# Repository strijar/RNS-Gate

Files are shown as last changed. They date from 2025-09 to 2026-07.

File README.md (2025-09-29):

# RNS-Gate

## Objective

Create a standalone device for access and routing within the Reticulum Network Stack 

## Interfaces for accessing other network nodes

* Integrated:
  - LoRa module (E22/E32 via SPI)
  - WiFi
  - Bluetooth
  - 10/100 Ethernet
* External:
  - RNode (via USB or Bluetooth)
  - WiFi in monitor mode (via USB)
* Audio access and PTT control for connecting analog VHF and HF radios with soft modem implementation 
* Connection of DMR stations via USB (OpenGD77 firmware) 

## Access to user devices

* BlueTooth 
* IP via WiFi and Ethernet

## Implementation

A 3-component "tower":

* Single-board computer based on Orange Pi Zero 
* Add-on board with an E22/E32 LoRa module 
* Add-on board with an HF/VHF audio interface

## Device configuration

Web interface over IP

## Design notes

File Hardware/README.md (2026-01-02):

# RNS-Gate Hardware

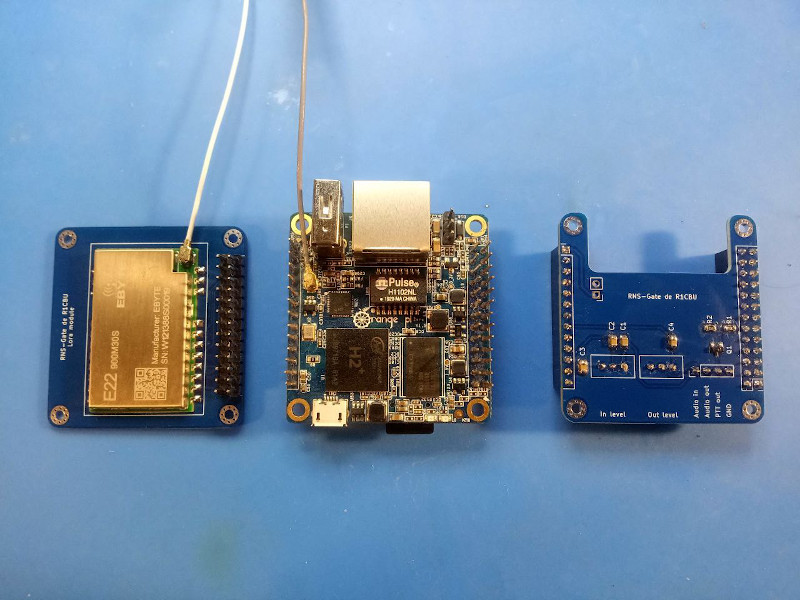
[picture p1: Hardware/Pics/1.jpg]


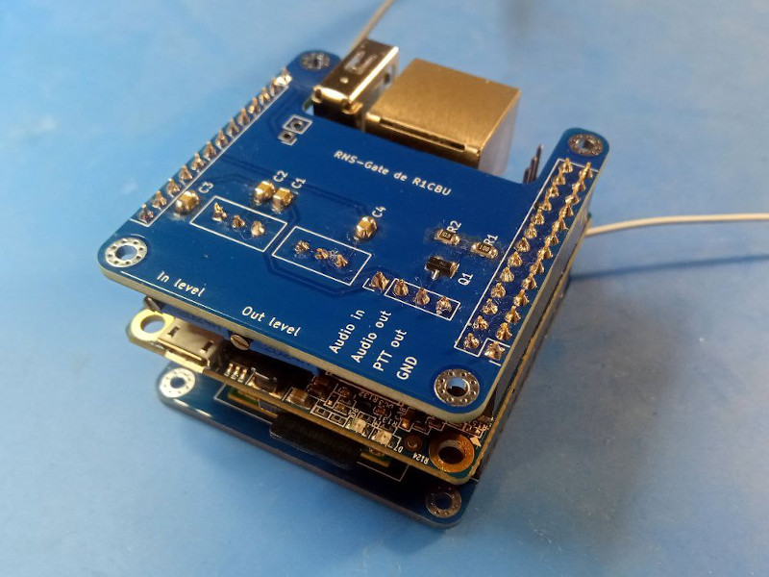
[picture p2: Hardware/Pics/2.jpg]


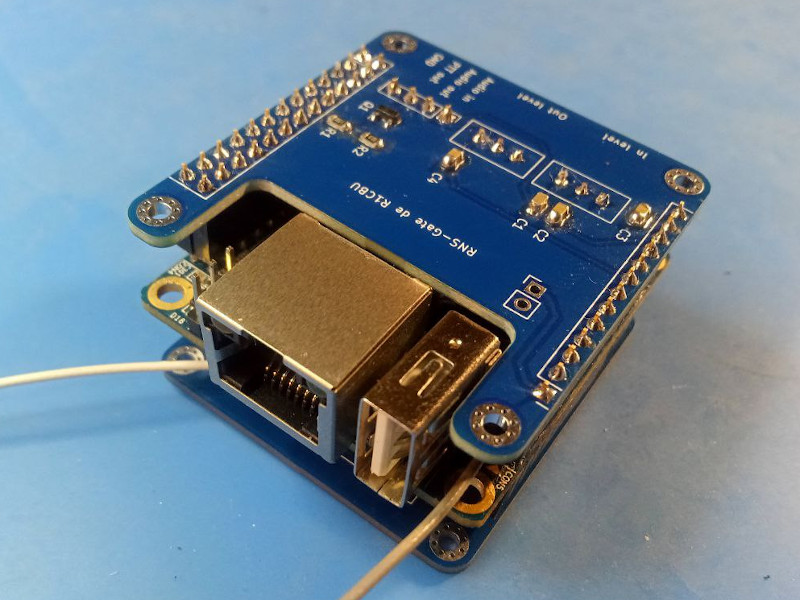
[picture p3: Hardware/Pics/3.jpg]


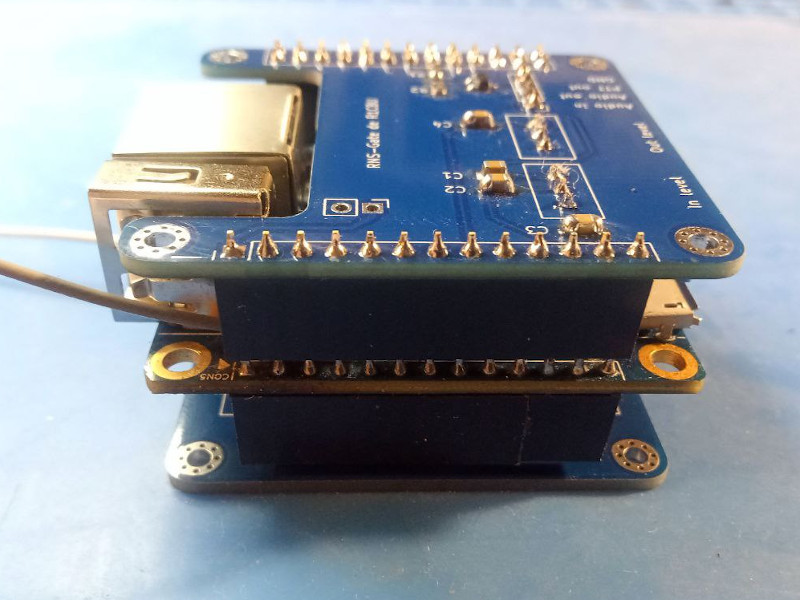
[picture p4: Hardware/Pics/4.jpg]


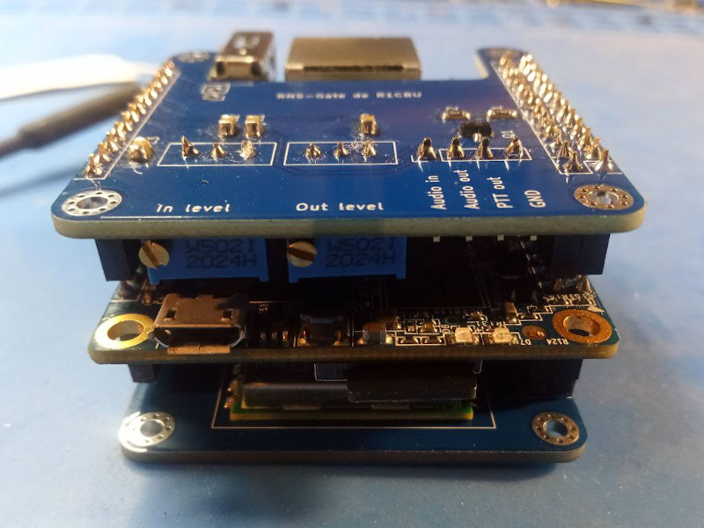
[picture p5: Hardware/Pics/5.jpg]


## Audio cable pinout

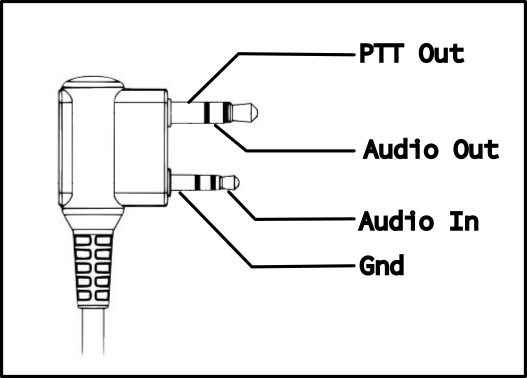
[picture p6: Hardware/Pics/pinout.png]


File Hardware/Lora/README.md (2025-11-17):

# RNS-Gate Hardware

## Lora module

### Pinout

| E22  | Orange Pi Zero |
|---|---|
| SPI  | SPI1 (PA13, PA14, PA15, PA16) |
| Busy | PA11 |
| NRST | PA06 |
| DIO1 | PA12 |
| DIO2 | PA19 |
| RXEN | PA02 |
| TXEN | PA18 |

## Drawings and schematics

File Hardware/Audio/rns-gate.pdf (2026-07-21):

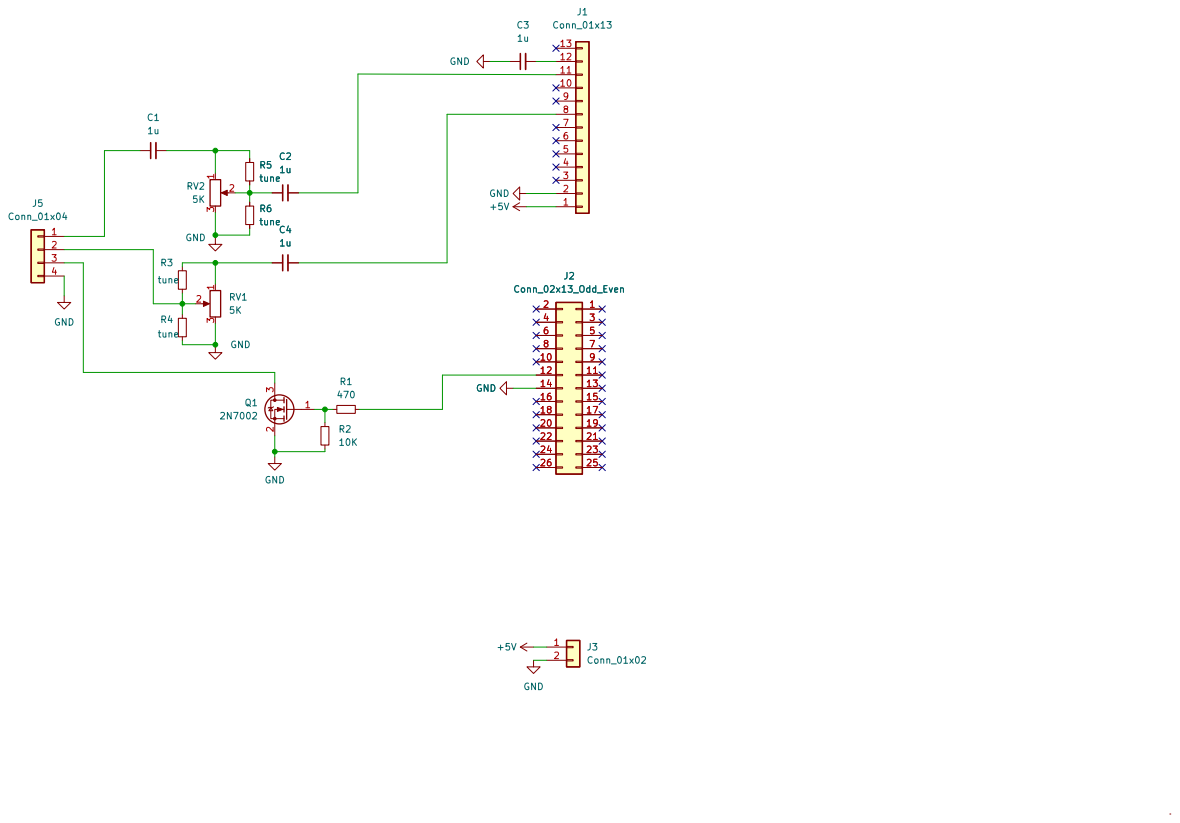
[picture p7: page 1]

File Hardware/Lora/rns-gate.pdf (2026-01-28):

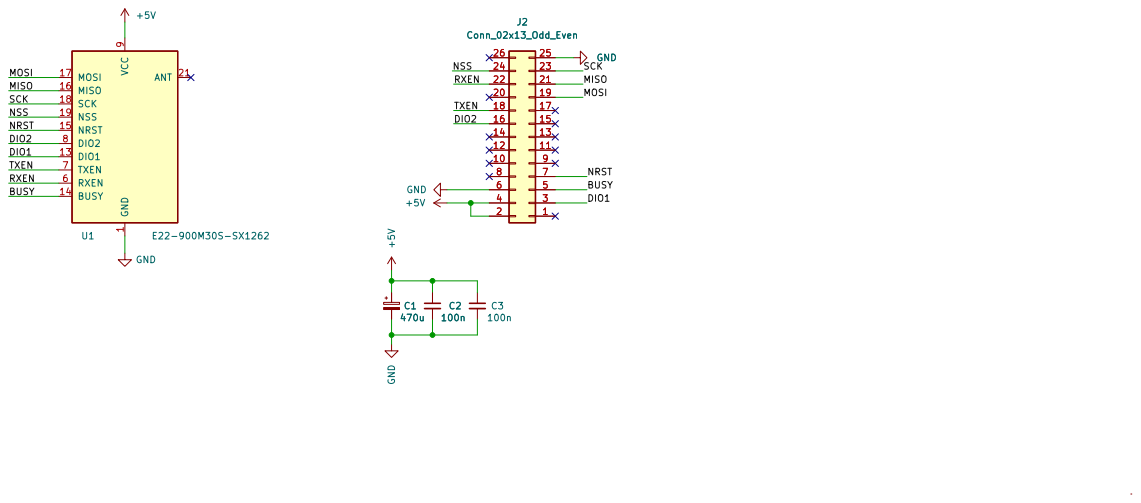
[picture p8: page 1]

SCK MISO MOSI SCK MISO
NSS NRST

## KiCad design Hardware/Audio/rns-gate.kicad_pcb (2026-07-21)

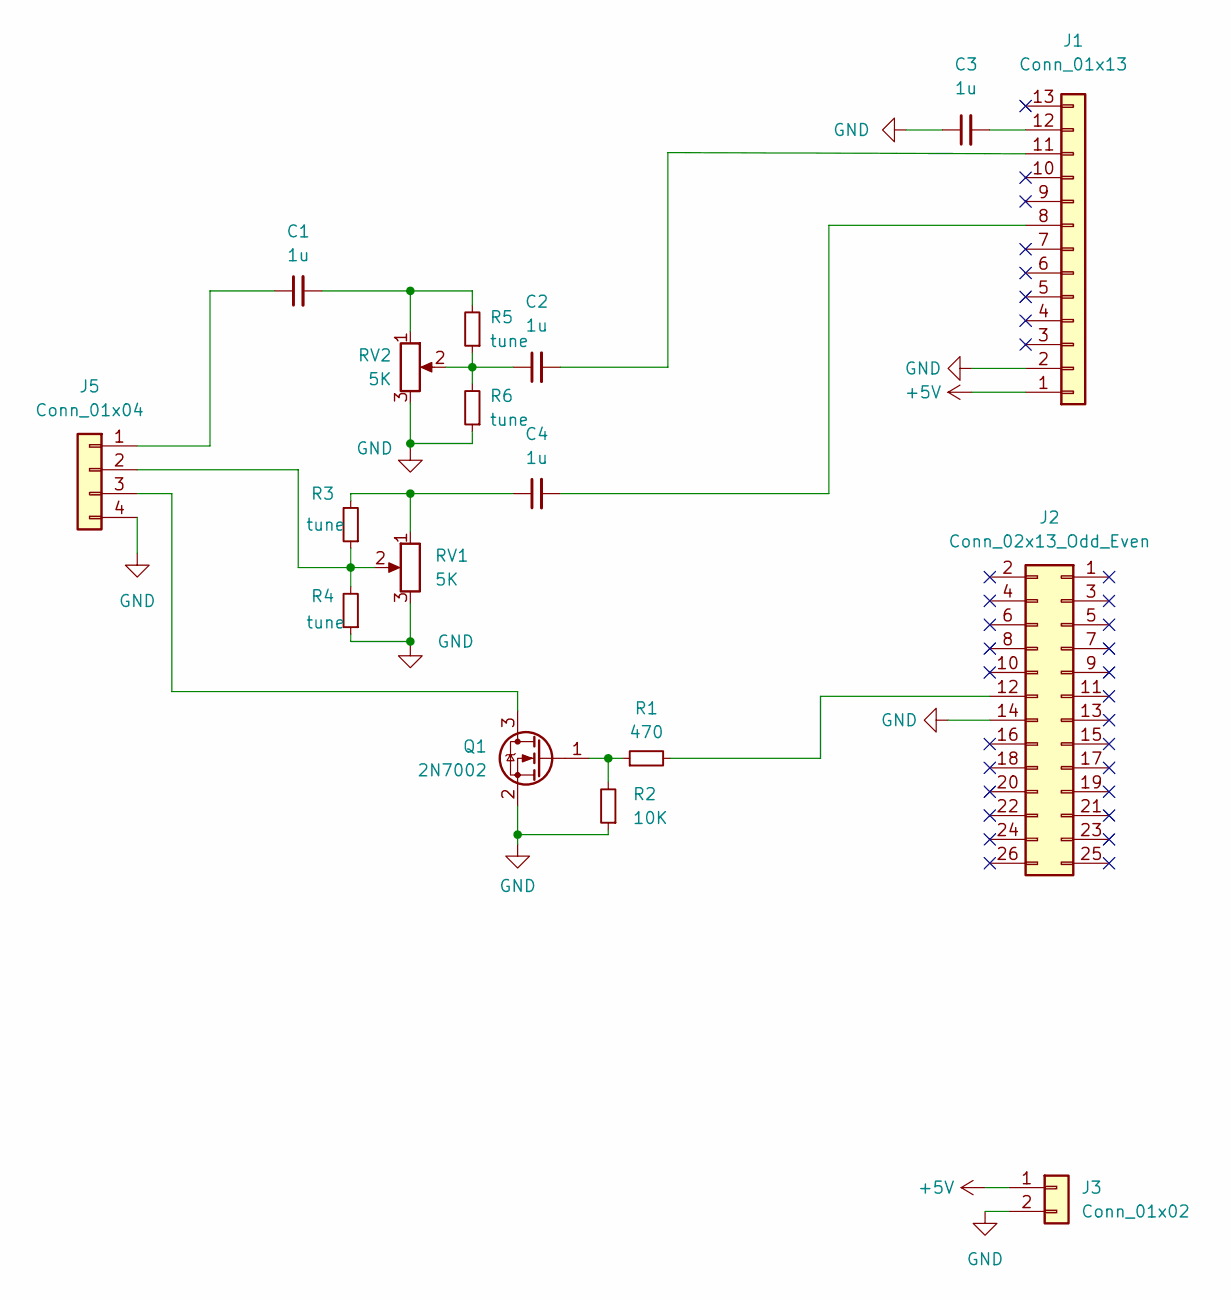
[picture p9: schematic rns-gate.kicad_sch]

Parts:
C1, C2, C3, C4: 1u; C_0805_2012Metric
J1: Conn_01x13; PinHeader_1x13_P2.54mm_Vertical
J2: Conn_02x13_Odd_Even; PinHeader_2x13_P2.54mm_Vertical
J3: Conn_01x02; PinHeader_1x02_P2.54mm_Vertical
J5: Conn_01x04; PinHeader_1x04_P2.54mm_Vertical
Q1: 2N7002; SOT-23
R1: 470; R_0805_2012Metric
R2: 10K; R_0805_2012Metric
R3, R4, R5, R6: tune; R_0805_2012Metric
RV1, RV2: 5K; Potentiometer_Bourns_3296W_Vertical

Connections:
+5V: J1.1, J3.1
GND: C3.1, J1.2, J2.14, J3.2, J5.4, Q1.2 (S), R2.1, R4.1, R6.1, RV1.3, RV2.3
unnamed: C2.1, R5.1, R6.2, RV2.2
unnamed: C2.2, J1.11
unnamed: C3.2, J1.12
unnamed: C4.1, R3.2, RV1.1
unnamed: C4.2, J1.8
unnamed: J2.12, R1.2
unnamed: C1.1, J5.1
unnamed: J5.3, Q1.3 (D)
unnamed: Q1.1 (G), R1.1, R2.2
unnamed: J5.2, R3.1, R4.2, RV1.2
unnamed: C1.2, R5.2, RV2.1

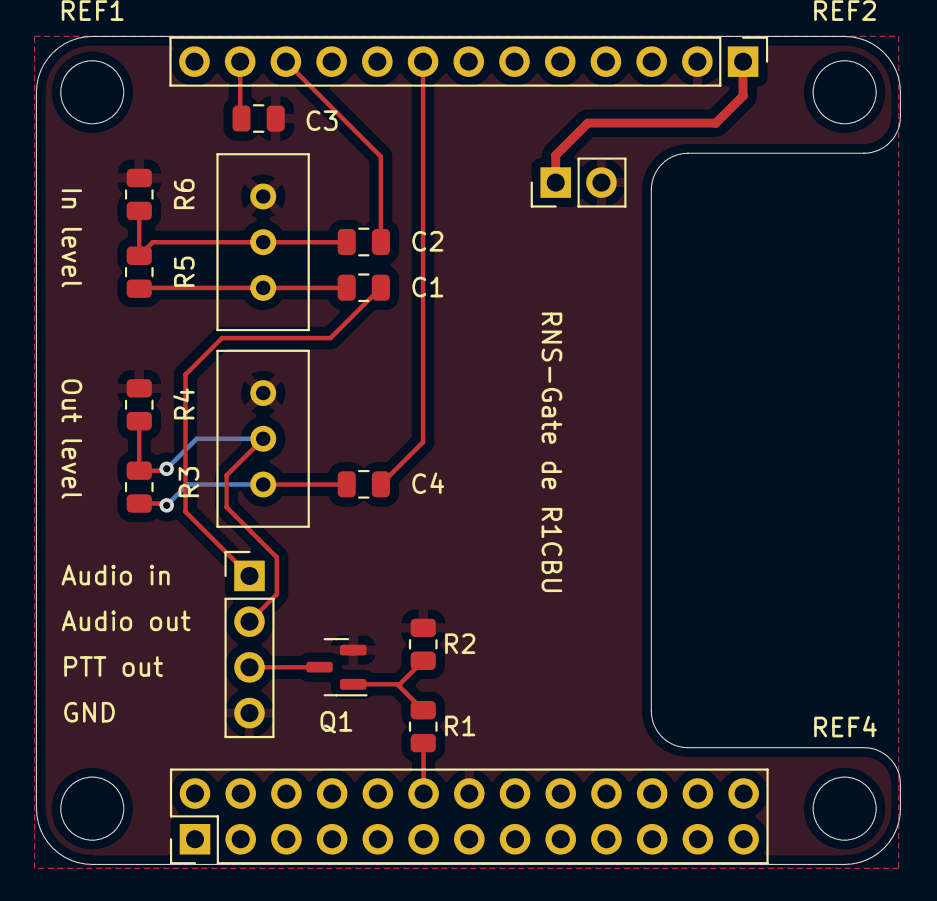
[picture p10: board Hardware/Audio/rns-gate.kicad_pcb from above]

Board: 2 copper layers, 48.0 x 46.0 mm, 21 parts (0 on the bottom side), 13 nets.

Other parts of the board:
REF1, REF2, REF3, REF4: MountingHole_3.5mm

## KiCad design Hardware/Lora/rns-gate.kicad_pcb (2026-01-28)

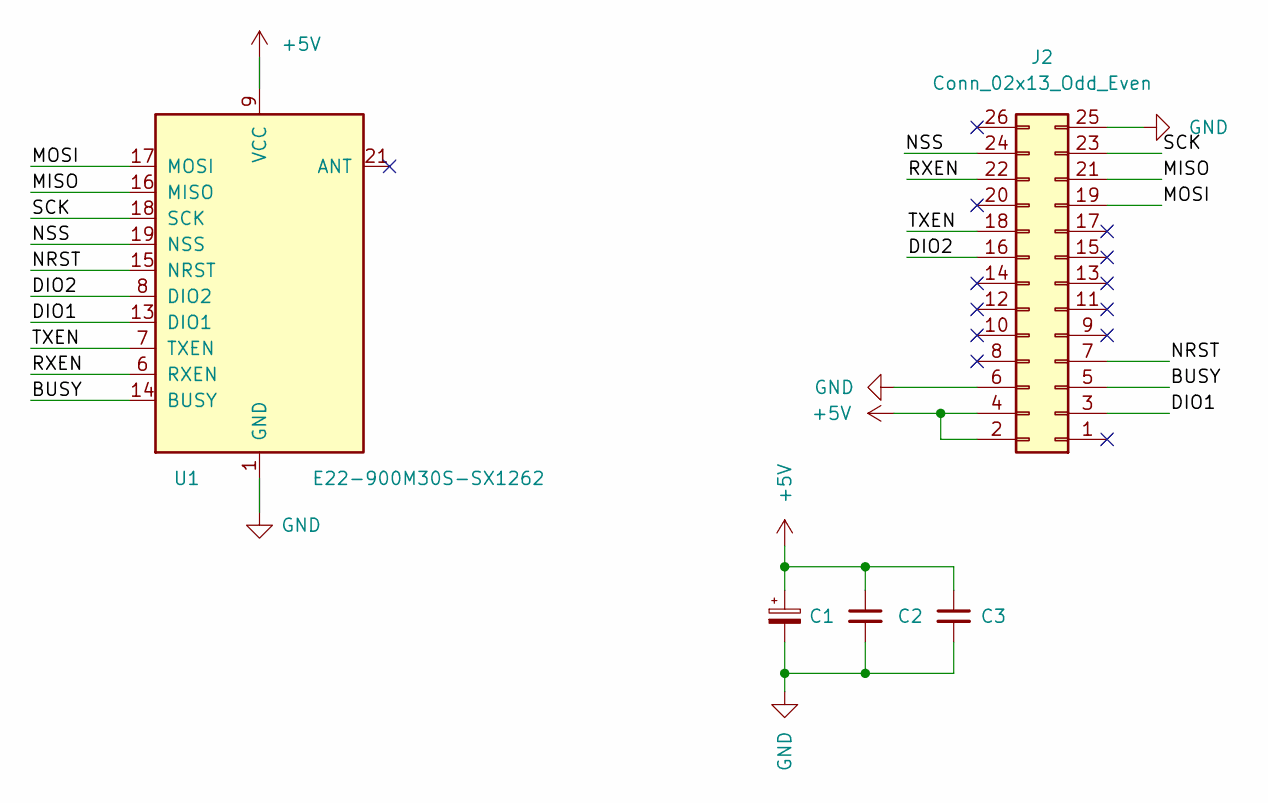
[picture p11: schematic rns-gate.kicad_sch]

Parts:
C1: C_Polarized_Small; CP_EIA-7343-43_Kemet-X_Pad2.25x2.55mm_HandSolder
C2, C3: C_Small; C_0805_2012Metric_Pad1.18x1.45mm_HandSolder
J2: Conn_02x13_Odd_Even; PinHeader_2x13_P2.54mm_Vertical
U1: E22-900M30S-SX1262

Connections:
+5V: C1.1, C2.1, C3.1, J2.2, J2.4, U1.9 (VCC), U1.10 (VCC)
/BUSY: J2.5, U1.14 (BUSY)
/DIO1: J2.3, U1.13 (DIO1)
/DIO2: J2.16, U1.8 (DIO2)
/MISO: J2.21, U1.16 (MISO)
/MOSI: J2.19, U1.17 (MOSI)
/NRST: J2.7, U1.15 (NRST)
/NSS: J2.24, U1.19 (NSS)
/RXEN: J2.22, U1.6 (RXEN)
/SCK: J2.23, U1.18 (SCK)
/TXEN: J2.18, U1.7 (TXEN)
GND: C1.2, C2.2, C3.2, J2.6, J2.25, U1.1 (GND), U1.2 (GND), U1.3 (GND), U1.4 (GND), U1.5 (GND), U1.11 (GND), U1.12 (GND), U1.20 (GND), U1.22 (GND)

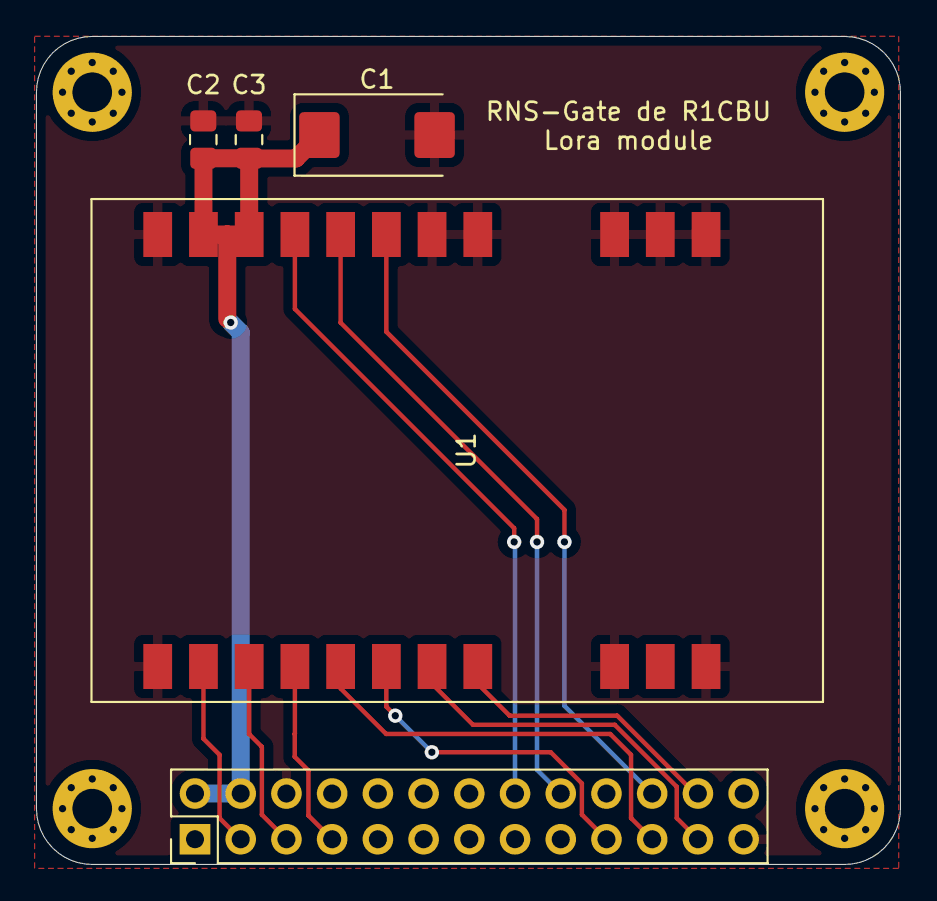
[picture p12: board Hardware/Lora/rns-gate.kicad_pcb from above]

Board: 2 copper layers, 48.0 x 46.0 mm, 9 parts (0 on the bottom side), 12 nets.

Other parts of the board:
REF1, REF2, REF3, REF4: MountingHole_2.2mm_M2_Pad_Via

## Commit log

2025-09-29 Fixes. Add rns package. Update config
    [genimage.cfg]
2025-10-31 Switch to Buildroot 2024.02
2025-11-01 Added hardware - Lora module
    [rns-gate-B_Mask.gbs, rns-gate-B_Paste.gbp, rns-gate-B_Silkscreen.gbo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]
2025-11-01 Added hardware - Audio module
    [rns-gate-B_Mask.gbs, rns-gate-B_Paste.gbp, rns-gate-B_Silkscreen.gbo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]
2025-11-13 Added PDF schematics
2025-12-07 Added packages, FAT part in image
    [genimage.cfg]
2025-12-16 Update start scripts
    [genimage.cfg]
2026-01-02 Added led control
2026-01-22 Added pos files for PCB
    [rns-gate-bottom-pos.csv, rns-gate-top-pos.csv]
2026-01-28 Update Lora module
    [rns-gate-B_Mask.gbs, rns-gate-B_Paste.gbp, rns-gate-B_Silkscreen.gbo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]
2026-01-28 Update Lora schematic
    [rns-gate.kicad_sch]
2026-07-21 Update Audio module
    [rns-gate-B_Mask.gbs, rns-gate-B_Paste.gbp, rns-gate-B_Silkscreen.gbo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]
